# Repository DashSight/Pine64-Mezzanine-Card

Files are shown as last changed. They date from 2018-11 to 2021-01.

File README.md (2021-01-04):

# Pine64 Mezzanine Card

OSH Open Source Hardware Logo
Qwiic Logo

This is a open source hardware mezzanine card/hat/expansion board for the [SOPINE A64](https://www.pine64.org/sopine/) Single Board Computer (SBC). The project is developed using the open source EDA tool [KiCAD](http://kicad-pcb.org/).

This card adds the following features to the Pine64 SBC:

* OBDII Connection to communicate with a car's onboard diagnostics
  * SAE J1850 PWM
  * SAE J1850 VPW
  * ISO 9141-2
  * ISO 14230 KWP2000
  * ISO 15765 CAN
* GPS receiver to obtain current location
  * Battery backup to reduce power up time
  * External powered antenna to increase accuracy
  * PPS to increase accuracy of clock
* Inertial Measurement Unit (IMU) to detect acceleration and body roll
  * Connected via SPI
* 3 x [Qwiic](https://www.sparkfun.com/qwiic) connectors to expose other devices via I2C
* Support for a [1 wire temperature sensor](https://www.sparkfun.com/products/11050)

The version 3.0 is baed on the [ELM327](https://www.elmelectronics.com/ic/elm327/), the [u-blox NEO-M9N](https://www.u-blox.com/en/product/neo-m9n-module) Integrate Circuits (ICs) and the [LSM9DS1 IMU](https://www.st.com/en/mems-and-sensors/lsm9ds1.html).

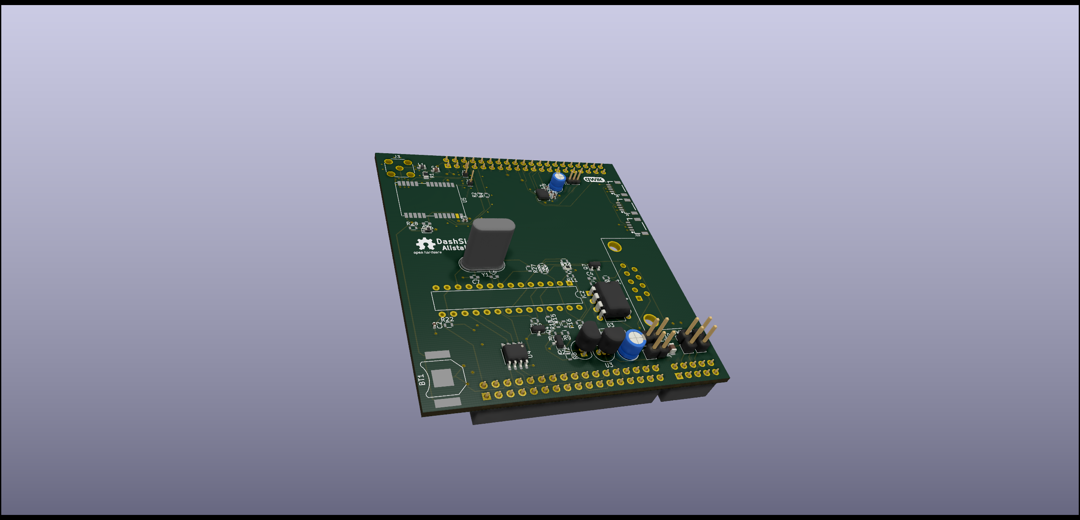
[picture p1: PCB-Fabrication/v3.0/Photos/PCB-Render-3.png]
DashSight Mezzanine Card v3.0 Render


## Licence

The design is licenced under the CERN-OHL-W licence.

The exception to this is the 3rd party [SparkFun libraries](https://github.com/sparkfun/SparkFun-KiCad-Libraries) which are used for the Qwiic connectors in the schematic and PCB. These are released under the [Creative Commons Attribution 4.0 International license](https://creativecommons.org/licenses/by/4.0/).

## v3.0 Production Run

More [pictures of v3.0](https://github.com/DashSight/Pine64-Mezzanine-Card/blob/master/PCB-Fabrication/v3.0/Photos) are avaliable

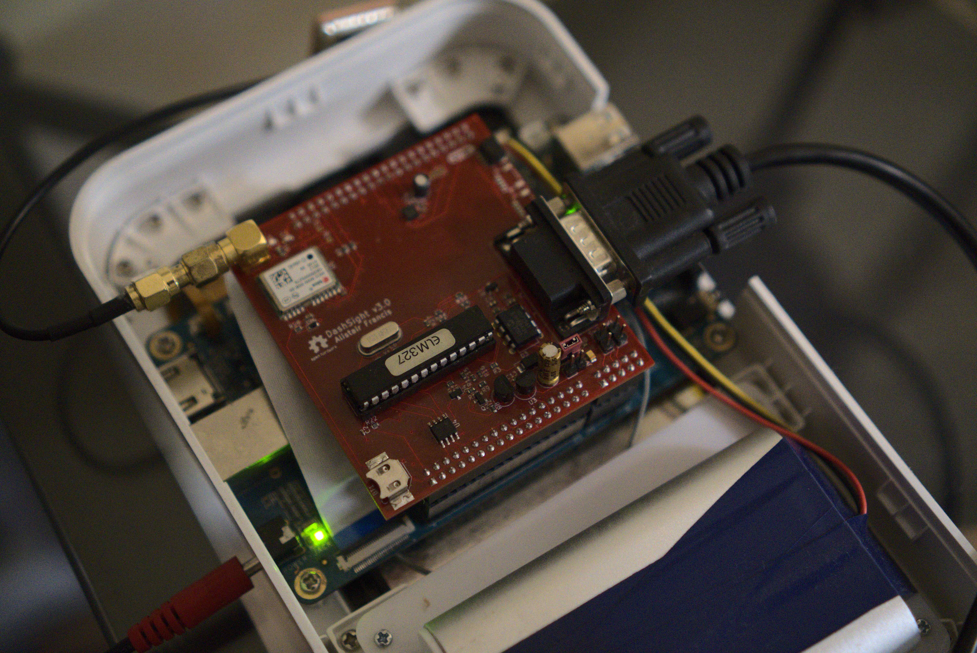
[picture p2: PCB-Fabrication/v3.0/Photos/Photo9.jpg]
DashSight Mezzanine Card Photo 9

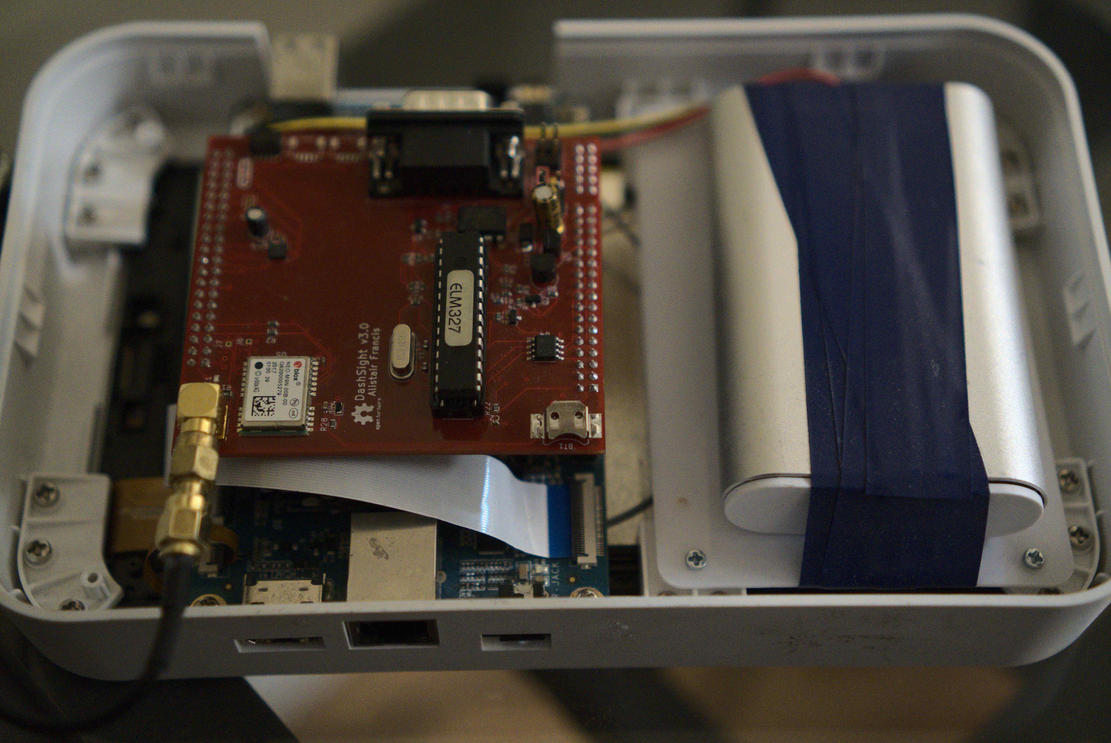
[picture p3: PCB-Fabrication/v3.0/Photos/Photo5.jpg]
DashSight Mezzanine Card Photo 5


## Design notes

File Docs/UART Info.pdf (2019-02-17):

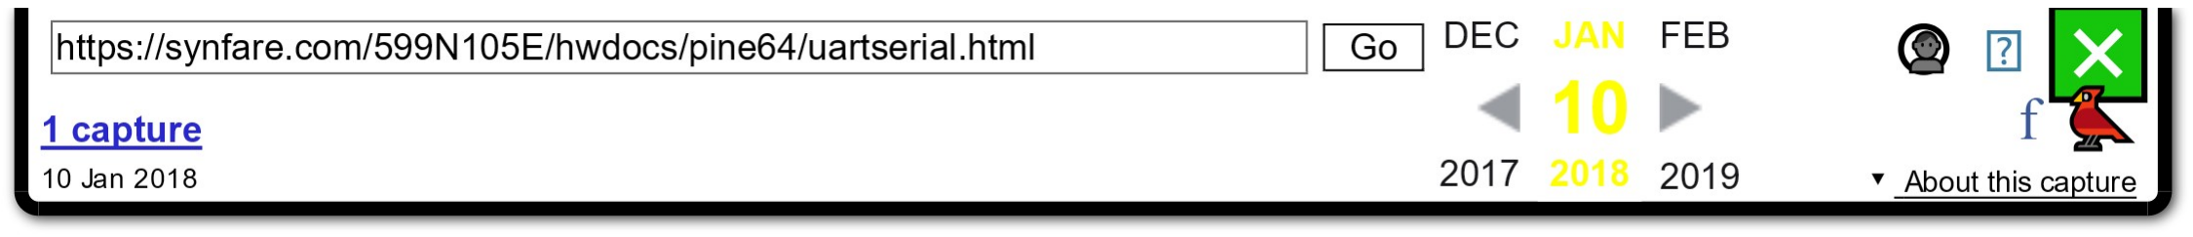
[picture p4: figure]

# UART Serial ports

There are 6 serial ports defined, of which at least 5 can operate with terminals or in any other way that serial ports can be used. Some of the ports have the RTS/CTS handshaking line pair also, as shown. UART0 TX and RX appear on both Euler (J48) and Expansion (J51). Ground connections refer to pins physically near the TX and RX pins; any other Ground pins can be used as well. The serial ports defined are available at the following pins:

UART#

/dev/ttyS# | Tx | Rx | RTS
| | | (output) | CTS
| | | | (input) | GND
0 | X7 | X8 | | | X6 | Voh = 3.3 V nominal. Gated so there is no
| | | | | | back-feeding when power is off.
0 | E29 | E30 | | | E34 | Voh = 3.3 V nominal
1 | B2 | B4 | B6 | B8 | B10 | Voh = 1.8 V nominal
2 | P8 | P10 | E11 | E27 | P6 | Voh = 3.3 V nominal
3 | E24 | E23 | | | E25 | Voh = 2.5 V nominal
3 | T2 | P29 | P31 | (P26) | P30 | Voh = 2.5 V nominal. Alternate connections
| | | | | | seen on some recent kernels. See discussion
| | | | | | below.
4 | E19 | E21 | E18 | E22 | E20 | Voh = 2.5 V nominal
S- | W9 | W11 | | | W12 | Voh = 1.8 V nominal
Adafruit USB cable (#954) | White
| (Rx) | Green
| | (Tx) | | | Black
| | | | | (Gnd) | (Red is 5V, NC)
Sparkfun USB cable (CAB-12977) | Yellow
| (Rx) | Orange
| | (Tx) | | | Black
| | | | | (Gnd) | (Red is 5V, NC)

Adafruit FTDI
Serial TTL-232 USB cable (#70) | Yellow
| (Rx) | Orange
| | (Tx) | Brown
| | | (CTS) | Green
| | | | (RTS) | Black
| | | | | (Gnd) | (Red is 5V, NC)
DE9M (DTE) pin # | 3 | 2 | 7 | 8 | 5 | (Via level translator)

DB25M (DTE)
pin # | 2 | 3 | 4 | 5 | 7 | (Via level translator)

The signal level on UARTs 0 and 2 is 3.3V, on UARTs 3 and 4 it is 2.5V, and on UARTs 1 and S it is 1.8 V. so the connections to a standard DE9 plug shown will have to be made via level translators in an ST3232 or similar that converts from RS-232 Mark and Space to H and L.

Pine A64+ UARTs | https://web.archive.org/web/20180110102911/https://synfare.com/599N...
1 of 2 | 10/02/2019, 9:33 pm

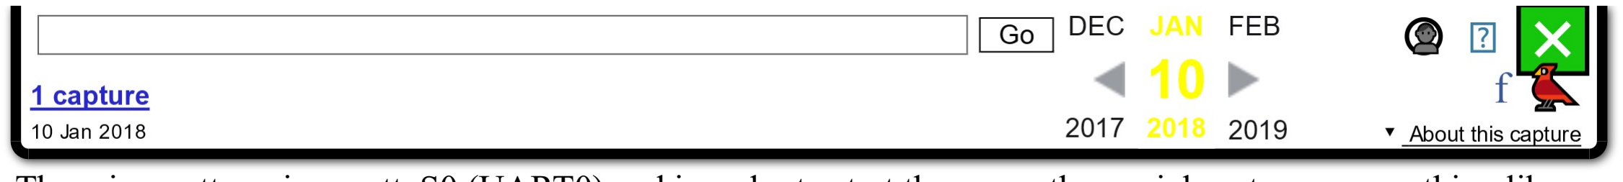
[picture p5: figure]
Note that UART1 (/dev/tty; output voltage is on the low

not be directly available if the wireless card is being used. These are also both in the 1.8 V system so the high

There is a getty going on ttyS0 (UART0) and in order to start these on other serial ports, use something like what is shown here for ttyS2 here:

systemctl enable serial-getty@ttyS2.service
systemctl start serial-getty@ttyS2.service

Similarly, in order to remove the getty the equivalent commands are:

systemctl stop serial-getty@ttyS2.service
systemctl disable serial-getty@ttyS2.service

### Where has uart3 moved?

2017-11-13: For some reason the /dev/ttyS3 seemed inoperative on the more recent kernels. (3.10.105-bsp-1.2-ayufan-118). Code for opening, writing and reading didn't fail, but nothing appeared on the wires. Some more investigation of the GPIO control registers for pins PD0 and PD1 showed that these two are at function 7 which means they are disabled. Notably, bits PD5, PD4, PD3, and PD2, which are associated with UART4, were at the expected function 3, which is the serial-port settings. Changing these settings to 3 for PD1 and PD0 was all that was needed for the UART3 to start emitting and receiving signals on the assigned wires, PD0 at pin E24 for transmission, and PD1 at pin E23 for reception.

Inspection of the device-tree file, indicates that the UART3 is actually enabled on PH4=Tx (T2) PH5=Rx (P29) PH6=RTS (P31) PH7=CTS (P26). Now that is somewhat less convenient since PH4, transmit data, is one of the Touchpad connector pins, identified as at connection T2. Unless this is broken out, it will not make the UART3 particularly useful... Besides that, the PH7 is already being used for a codec output of some sort, and is being allocated, as per /sys/kernel/debug/gpio.

The file checku.c contains the code I used for performing this check and making the changes. This code is similar to what is shown on the page for /dev/mem gpio handling.

This function shows the functions of all the first 8 PD and PH ports, PD7 (GPIO103, at pin E28) and PD6 (GPIO102 at pin E26) are shown as function 7, disabled, also. This makes sense, since these are unallocated, and available for us to use. PH7 (GPIO231 at pin P26) shows as 1, output, and the rest of PH6-PH0 are function 2. Now for PH3-PH0 this function means they operate as the two i2c busses, so that has to remain the same!

Now, it turns out, that when any gpio not otherwise allocated, is exported via sysfs (see the sysfs gpio details), its function is not changed. So if it started out as disabled, it remains disabled, even though the direction file (/sys/class/gpio/gpio103/direction) says "in". Only when this direction file is written with the values "in" or "out" does this register value change, to 0 for input and 1 for output. (
Allwinner_A64_User_Manual_V1.0.pdf, section 3.21.2.19, page 384) These settings also remain after the gpio is unexported, and thus a gpio will have the same direction after another exporting as it had before. This was noted as a kind of bug in the forum. To Pine 64+ main page

Powered by Apache

Valid XHTML 1.0!

Pine A64+ UARTs | https://web.archive.org/web/20180110102911/https://synfare.com/599N...
2 of 2 | 10/02/2019, 9:33 pm

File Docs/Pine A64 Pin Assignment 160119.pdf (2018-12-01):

Pi-2 Connector

Page 1

Pi-2 Connector
| | 3.3V | | 1 | 2 | | | 5V
PH3 | TWI1_SDA GPIO 2 | I2C1_SDA | 3 | 4 | 5V
PH2 | TWI1_SCK GPIO 3 | I2C1_SCL | 5 | 6 | GND
PL10 | S_PWM | GPIO 4 | GPCLK0 | 7 | 8 | UART_TXD GPIO 14 | UART2_TX PB0
GND | 9 | 10 | UART_RXD GPIO 15 | UART2_RX PB1
PC7 | | GPIO 17 | | 11 | 12 | | GPIO 18 | | PC8
PH9 | | GPIO 27 | | 13 | 14 | | | GND
PC12 | | GPIO 22 | | 15 | 16 | | GPIO 23 | | PC13
| | 3.3V | | 17 | 18 | | GPIO 24 | | PC14
PC0 | SPI0_MOSI GPIO 10 | SPI_MOSI | 19 | 20 | GND
PC1 | SPI0_MISO GPIO 9 | SPI_MISO | 21 | 22 | GPIO 25 | PC15
PC2 | SPI0_CLK | GPIO 11 | SPI_SCLK | 23 | 24 | SPI_CE0 | GPIO 8 | SPI0_CS | PC3
| | GND | | 25 | 26 | SPI_CE1 | GPIO 7 | | PH7
PL9 | TWI_SDA | | ID_SD | 27 | 28 | ID_SC | | TWI_SCK | PL8
PH5 | | GPIO 5 | | 29 | 30 | | | GND
PH6 | | GPIO 6 | | 31 | 32 | | GPIO 12 | | PC4
PC5 | | GPIO 13 | | 33 | 34 | | | GND
PC9 | | GPIO 19 | | 35 | 36 | | GPIO 16 | | PC6
PC16 | | GPIO 26 | | 37 | 38 | | GPIO 20 | | PC10
| | GND | | 39 | 40 | | GPIO 21 | | PC11

Euler "e" Connector

Page 2

Euler "e" Connector
| | 3.3V | 1 | 2 | DC IN
Lithium Batt+ | 3 | 4 | DC IN
Temp Sensor | 5 | 6 | GND
PL11 | IR_RX | | 7 | 8 | 5V
GND | 9 | 10 | SPDIF | OWA_OUT PH8
PB3 | I2S_MCK | | 11 | 12 | I2S_SYNC | PB4
PB5 | I2S_BCK | | 13 | 14 | GND
PB6 | I2S_DOUT | | 15 | 16 | I2S_DIN | PB7
3.3V | 17 | 18 | UART4_RTS PD4
PD2 | SPI1_MOSI UART4_TX | 19 | 20 | GND
PD3 | SPI1_MISO UART4_RX | 21 | 22 | UART4_CTS PD5
PD1 | SPI1_CLK | UART3_RX | 23 | 24 | UART3_TX SPI1_CS | PD0
| | GND | 25 | 26 | | PD6
PB2 | | | 27 | 28 | | PD7
PB8 | | UART0_TX | 29 | 30 | UART0_RX | PB9
EAROUTP | 31 | 32 | EAROUT_N
N.C. | 33 | 34 | GND

Exp Connector

Page 3

Exp Connector
3.3V | 1 | 2 | System LED | PL7
Charger LED | 3 | 4 | Reset Sw
Pwr/Stb Sw | 5 | 6 | GND
PB8 | UART0_TX | 7 | 8 | UART0_RX PB9
GND | 9 | 10 | KeyADC

Wifi_BT

Page 4

Wifi/BT Connector
GND | 1 | 2 | BT-UART-RX | UART1-TX | PG6
PG0 | SDC1-CK | SDIO-CLK | 3 | 4 | BT-UART-TX | | UART1-RX | PG7
GND | 5 | 6 | BT-UART-CTS | UART1-RTS PG8
PG1 | SDC1-CMD | SDIO-CMD | 7 | 8 | BT-UART-RTS | UART1-CTS PG9
PG2 | SDC1-D0 | SDIO-D0 | 9 | 10 | BT-PCM-SYNC | PCB1-SYNC AIF3-SYNC PG10
PG3 | SDC1-D1 | SDIO-D1 | 11 | 12 | BT-PCM-CLK | PCB1-BCLK AIF3-BCLK | PG11
PG4 | SDC1-D2 | SDIO-D2 | 13 | 14 | BT-PCM-DIN | PCB1-DOUT AIF3-DOUT PG12
PG5 | SDC1-D3 | SDIO-D3 | 15 | 16 | BT-PCM-DOUT | PCB1-DIN | AIF3-DIN | PG13
PL2 | S-UART-TX | WL-REG-ON | 17 | 18 | | GND
PL3 | S-UART-RX | WL-WAKE-AP | 19 | 20 | BT-WAKE-AP | S-JTAG-CK PL5
X32KFOUT | AP-CK32KO | 21 | 22 | BT-RST-N | S-JTAG-MS PL4
GND | 23 | 24 | AP-WAKE-BT | S-JTAG-DO PL6
VCC | 25 | 26 | IOVCC

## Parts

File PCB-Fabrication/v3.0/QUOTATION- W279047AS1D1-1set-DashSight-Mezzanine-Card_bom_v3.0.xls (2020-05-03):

Reference | Value | Footprint | Part Number | Field4 | Amount | 1sets | Total | update
IC2 | ELM327 | Housings_DIP:DIP-28_W7.62mm | ED281DT |  | 1 | $0.525 | $0.525 | ED281DT
Y1 | 4.0MHz | Crystals:Crystal_HC49-U_Vertical | ECS-040-20-4X-DU |  | 1 | $1.260 | $1.260 | 5-7work days
C6 | 27pF | Capacitors_SMD:C_0603 | CC0603JRNPO9BN270 |  | 1 | $0.525 | $0.525
C7 | 27pF | Capacitors_SMD:C_0603 | CC0603JRNPO9BN270 |  | 1 | $0.525 | $0.525
U1 | MCP2561-E/P | Housings_DIP:DIP-8_W7.62mm | MCP2561-E/P |  | 1 | $1.890 | $1.890 | 5-7work days
C2 | 0.1uF | Capacitor_SMD:C_0402_1005Metric | CC0402KRX7R7BB104 |  | 1 | $0.525 | $0.525
R3 | 4.7K | Resistors_SMD:R_0603 | RC0603FR-074K7L |  | 1 | $0.315 | $0.315
J4 | OBD2-DB9_Male | Connector_Dsub:DSUB-9_Male_Horizontal_P2.77x2.84mm_EdgePinOffset4.94mm_Housed_MountingHolesOffset7.48mm | A-DS 09 A/KG-T2S |  | 1 | $1.575 | $1.575 | 5-7work days
R5 | 100 | Resistors_SMD:R_0603 | RC0603JR-07100RL |  | 1 | $0.315 | $0.315
R6 | 100 | Resistors_SMD:R_0603 | RC0603JR-07100RL |  | 1 | $0.315 | $0.315
C3 | 560pF | Capacitors_SMD:C_0603 | C0603C561K5RACTU |  | 1 | $0.525 | $0.525
C4 | 560pF | Capacitors_SMD:C_0603 | C0603C561K5RACTU |  | 1 | $0.525 | $0.525
R11 | 47K | Resistors_SMD:R_0603 | RC0603JR-0747KL |  | 1 | $0.315 | $0.315
R12 | 10K | Resistor_SMD:R_0603_1608Metric | RC0603FR-0710KL |  | 1 | $0.315 | $0.315
U2 | LM317L_TO92 | TO_SOT_Packages_THT:TO-92_Inline_Narrow_Oval | LM317LZX |  | 1 | $1.050 | $1.050 | 5-7work days
R15 | 2.2K | Resistors_SMD:R_0603 | RC0603JR-072K2L |  | 1 | $0.315 | $0.315
R16 | 1.8K | Resistors_SMD:R_0603 | RC0603FR-071K8L |  | 1 | $0.525 | $0.525
R13 | 470 | Resistors_SMD:R_0603 | RC0603JR-07470RL |  | 1 | $0.315 | $0.315
R8 | 470 | Resistors_SMD:R_0603 | RC0603JR-07470RL |  | 1 | $0.315 | $0.315
Q2 | 2N3906 | Package_TO_SOT_SMD:SOT-23 | MMBT3904 |  | 1 | $0.525 | $0.525
R9 | 10K | Resistors_SMD:R_0603 | RC0603FR-0710KL |  | 1 | $0.315 | $0.315
D1 | 1N4148 | Diodes_SMD:D_SOD-123 | 1N4148W-TP |  | 1 | $0.525 | $0.525
R17 | 4.7K | Resistors_SMD:R_0603 | RC0603FR-074K7L |  | 1 | $0.315 | $0.315
Q4 | 2N3904 | Package_TO_SOT_SMD:SOT-23 | MMBT3904 |  | 1 | $0.525 | $0.525
R20 | 4.7K | Resistors_SMD:R_0603 | RC0603FR-074K7L |  | 1 | $0.315 | $0.315
R18 | 10K | Resistors_SMD:R_0603 | RC0603FR-0710KL |  | 1 | $0.315 | $0.315
R10 | 22K | Resistors_SMD:R_0603 | RC0603FR-0722KL |  | 1 | $0.315 | $0.315
R21 | 10K | Resistors_SMD:R_0603 | RC0603FR-0710KL |  | 1 | $0.315 | $0.315
R23 | 22K | Resistors_SMD:R_0603 | RC0603FR-0722KL |  | 1 | $0.315 | $0.315
Q3 | 2N3906 | Package_TO_SOT_SMD:SOT-23 | MMBT3904 |  | 1 | $0.525 | $0.525
R22 | 4.7K | Resistors_SMD:R_0603 | RC0603FR-074K7L |  | 1 | $0.315 | $0.315
R19 | 10K | Resistors_SMD:R_0603 | RC0603FR-0710KL |  | 1 | $0.315 | $0.315
R14 | 47K | Resistors_SMD:R_0603 | RC0603JR-0747KL |  | 1 | $0.315 | $0.315
D2 | 1N4148 | Diodes_SMD:D_SOD-123 | 1N4148W-TP |  | 1 | $0.525 | $0.525
Q1 | 2N3904 | Package_TO_SOT_SMD:SOT-23 | MMBT3904 |  | 1 | $0.525 | $0.525
Q5 | 2N3904 | Package_TO_SOT_SMD:SOT-23 | MMBT3904 |  | 1 | $0.525 | $0.525
R7 | 4.7K | Resistors_SMD:R_0603 | RC0603FR-074K7L |  | 1 | $0.315 | $0.315
Q6 | 2N3904 | Package_TO_SOT_SMD:SOT-23 | MMBT3904 |  | 1 | $0.525 | $0.525
R24 | 2.2K | Resistors_SMD:R_0603 | RC0603JR-072K2L |  | 1 | $0.315 | $0.315
R29 | 510 | Resistors_SMD:R_0603 | RC0603JR-07510RL |  | 1 | $0.315 | $0.315
Q7 | 2N3904 | Package_TO_SOT_SMD:SOT-23 | MMBT3904 |  | 1 | $0.525 | $0.525
R25 | 2.2K | Resistors_SMD:R_0603 | RC0603JR-072K2L |  | 1 | $0.315 | $0.315
R30 | 510 | Resistors_SMD:R_0603 | RC0603JR-07510RL |  | 1 | $0.315 | $0.315
R26 | 47K | Resistors_SMD:R_0603 | RC0603JR-0747KL |  | 1 | $0.315 | $0.315
R27 | 33K | Resistors_SMD:R_0603 | CRCW060333K0FKEAC |  | 1 | $0.525 | $0.525
D3 | 1N5819 | Diodes_SMD:D_SMA | 1N5819 |  | 1 | $0.525 | $0.525
J1 | Pi2 Connector | Pin_Headers:Pin_Header_Straight_2x20_Pitch2.54mm | PPPC202LFBN-RC |  | 1 | $1.050 | $1.050
J2 | Euler Connector | Pin_Headers:Pin_Header_Straight_2x17_Pitch2.54mm | PPPC172LFBN-RC |  | 1 | $1.050 | $1.050
C8 | 0.1uF | Capacitors_SMD:C_0402 | CC0402KRX7R7BB104 |  | 1 | $0.525 | $0.525
C12 | 2.2uF 50V | Capacitor_THT:CP_Radial_D5.0mm_P2.50mm | UFW1H2R2MDD1TD |  | 1 | $0.840 | $0.840 | 5-7work days
C13 | 0.1uF 50V | Capacitor_SMD:C_0402_1005Metric | UMK105BJ104KV-F |  | 1 | $0.525 | $0.525
U3 | LP2950-3.0_TO92 | Package_TO_SOT_THT:TO-92_Inline | LP2950-50LPRE3 |  | 1 | $1.050 | $1.050 | 3300pcs in stock
C10 | 0.1uF | Capacitor_SMD:C_0402_1005Metric | CC0402KRX7R7BB104 |  | 1 | $0.525 | $0.525
C11 | 4.7uF 10V | Capacitor_SMD:C_0805_2012Metric | TAJR475M010RNJ |  | 1 | $0.840 | $0.840 | 2500pcs in stock
U4 | ADuM1201AR | Housings_SOIC:SOIC-8_3.9x4.9mm_Pitch1.27mm | ADuM1201AR |  | 1 | $2.100 | $2.100 | provide ADUM1201ARZ-RL7
JP2 | Vbat-JP | Pin_Headers:Pin_Header_Straight_1x02_Pitch2.54mm | 61300211121 |  | 1 | $0.315 | $0.315
JP1 | DCIn-JP | Pin_Headers:Pin_Header_Straight_1x02_Pitch2.54mm | 61300211121 |  | 1 | $0.315 | $0.315
R2 | 470 | Resistors_SMD:R_0603 | RC0603JR-07470RL |  | 1 | $0.315 | $0.315
D4 | 0.5A/40V/420mV | Resistors_SMD:R_0402 | VSKY05401006-G4-08 |  | 1 | $1.155 | $1.155 | RB551SS-30T2R size 0603 5-7work days
BT1 | 6.8mm-Coin-Cell | DashSight-PCB-Footprints:BatteryHolder_Keystone_2998_1x6.8mm | 2998 |  | 1 | $1.050 | $1.050 | 5-7work days
C14 | 1uF | Capacitors_SMD:C_0603 | CC0603ZRY5V7BB105 |  | 1 | $0.525 | $0.525
U5 | NEO-M9N | RF_GPS:ublox_NEO | https://www.u-blox.com/sites/default/files/NEO-M8-FW3_DataSheet_%28UBX-15031086%29.pdf |  | 1 | $35.000 | $35.000 | NEO-M9N two weeks
R4 | 470 | Resistors_SMD:R_0603 | RC0603JR-07470RL |  | 1 | $0.315 | $0.315
R28 | 1K | Resistors_SMD:R_0603 | RC0603FR-071KL |  | 1 | $0.525 | $0.525
J5 | Conn_02x05_Odd_Even | Connector_PinHeader_2.54mm:PinHeader_2x05_P2.54mm_Vertical | PPPC052LFBN-RC |  | 1 | $0.525 | $0.525
SW1 | SW_Push | Connector_PinHeader_2.54mm:PinHeader_1x02_P2.54mm_Vertical | 61300211121 |  | 1 | $0.315 | $0.315
SW2 | SW_Push | Connector_PinHeader_2.54mm:PinHeader_1x02_P2.54mm_Vertical | 61300211121 |  | 1 | $0.315 | $0.315
R1 | 10 | Resistor_SMD:R_0805_2012Metric | SR0805KR-7W10RL |  | 1 | $0.330 | $0.330 | 3-4work days
C1 | 47pF | Capacitor_SMD:C_0603_1608Metric | C0603C104M4RACTU |  | 1 | $0.525 | $0.525
J3 | Conn_Coaxial | Connectors:SMA_THT_Jack_Straight | CONREVSMA002-G |  | 1 | $5.040 | $5.040 | 5-7work days
L1 | 30Ohm/1.8A | Inductor_SMD:L_0603_1608Metric | 744786127A |  | 1 | $0.840 | $0.840 | 5-7work days
C5 | 0.1uF | Capacitor_SMD:C_0402_1005Metric | CC0402KRX7R7BB104 |  | 1 | $0.525 | $0.525
U6 | LSM9DS1 | Package_LGA:LGA-24L_3x3.5mm_P0.43mm | LSM9DS1 |  | 1 | $5.250 | $5.250 | provide LSM9DS1TR
C18 | 10uF | Capacitor_THT:CP_Radial_D4.0mm_P1.50mm | UMP1A100MDD1TP |  | 1 | $1.260 | $1.260 | 5-7work days
C17 | 0.1uF | Capacitor_SMD:C_0402_1005Metric | CC0402KRX7R7BB104 |  | 1 | $0.525 | $0.525
C9 | 10nF (16V) | Capacitor_SMD:C_0402_1005Metric | C0402C103K4RACTU |  | 1 | $0.525 | $0.525
C15 | 0.1uF | Capacitor_SMD:C_0402_1005Metric | CC0402KRX7R7BB104 |  | 1 | $0.525 | $0.525
C16 | 0.1uF | Capacitor_SMD:C_0402_1005Metric | CC0402KRX7R7BB104 |  | 1 | $0.525 | $0.525
R38 | 2.2K | Resistor_SMD:R_0603_1608Metric | RC0603FR-072K2L |  | 1 | $0.315 | $0.315
R37 | 2.2K | Resistor_SMD:R_0603_1608Metric | RC0603FR-072K2L |  | 1 | $0.315 | $0.315
J7 | Reset | Connector_PinHeader_1.00mm:PinHeader_1x01_P1.00mm_Vertical |  |  | 1 | $0.000 | $0.000 | DNP
J6 | Safeboot | Connector_PinHeader_1.00mm:PinHeader_1x01_P1.00mm_Vertical |  |  | 1 | $0.000 | $0.000 | DNP
J8 | QWIIC_CONNECTORJS-1MM | DashSight:qwiic_connector | PRT-14417-ND | Qwiic0 | 1 | $1.365 | $1.365 | PRT-14417 7-10work days
J9 | QWIIC_CONNECTORJS-1MM | DashSight:qwiic_connector | PRT-14417-ND | Qwiic3 | 1 | $1.365 | $1.365 | PRT-14417 7-10work days
J10 | QWIIC_CONNECTORJS-1MM | DashSight:qwiic_connector | PRT-14417-ND | Qwiic1 | 1 | $1.365 | $1.365 | PRT-14417 7-10work days
J14 | 1W-PC16 | Connector_PinHeader_1.27mm:PinHeader_1x03_P1.27mm_Vertical |  |  | 1 | $0.000 | $0.000 | DNP
 |  |  |  |  |  | 1SET | $92.555
 |  |  |  |  |  | provide according to Part Number

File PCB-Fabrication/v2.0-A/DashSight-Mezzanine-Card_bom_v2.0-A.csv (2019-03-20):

Component | Description | Part | References | Value | Footprint | Quantity Per PCB | Datasheet
1 | Single-cell battery | Battery_Cell | BT1 | 6.8mm-Coin-Cell | BatteryHolder_Keystone_2998_1x6.8mm | 1 | 2998
2 | Polarized capacitor, US symbol | CP1 | C2 C5 C8 C10 | 0.1uF | C_0402 | 4 | CC0402KRX7R7BB104
3 | Polarized capacitor, US symbol | CP1 | C13 | 0.1uF 50V | C_0402 | 1 | UMK105BJ104KV-F
4 | Polarized capacitor, US symbol | CP1 | C1 C9 C14 | 1uF | C_0603 | 3 | CC0603ZRY5V7BB105
5 | Polarized capacitor, US symbol | CP1 | C12 | 2.2uF 50V | CP_Radial_D5.0mm_P2.50mm | 1 | UFW1H2R2MDD1TD
6 | Polarized capacitor, small US symbol | CP1_Small | C6 C7 | 27pF | C_0603 | 2 | CC0603JRNPO9BN270
7 | Polarized capacitor, US symbol | CP1 | C11 | 4.7uF 10V | C_0805 | 1 | TAJR475M010RNJ
8 | Polarized capacitor, US symbol | CP1 | C3 C4 | 560pF | C_0603 | 2 | C0603C561K5RACTU
9 | Schottky diode | D_Schottky | D4 | 0.5A/40V/420mV | R_0402 | 1 | VSKY05401006-G4-08
10 | Diode | D | D1 D2 | 1N4148 | D_SOD-123 | 2 | 1N4148W-TP
11 | Diode | D | D3 | 1N5819 | D_SMA | 1 | 1N5819
12 | Ferrite bead | Ferrite_Bead | FB1 | 600Ohm/100MHz | L_0402 | 1 | 74279279
13 |  | ELM327 | IC2 | ELM327 | DIP-28_W7.62mm | 1 | ED281DT
14 |  | XM1110 | IC1 | XM1110 | Sierra_XM11X0 | 1 | XM1110_1103886
15 | coaxial connector (BNC, SMA, SMB, SMC, Cinch/RCA, ...) | Conn_Coaxial | J3 | Conn_Coaxial | SMA_THT_Jack_Straight | 1 | CONREVSMA002-G
16 | Generic connector, double row, 02x17, odd/even pin numbering scheme (row 1 odd numbers, row 2 even numbers), script generated (kicad-library-utils/schlib/autogen/connector/) | Conn_02x17_Odd_Even | J2 | Euler Connector | Pin_Header_Straight_2x17_Pitch2.54mm | 1 | PPPC172LFBN-RC
17 | Generic connector, double row, 02x20, odd/even pin numbering scheme (row 1 odd numbers, row 2 even numbers), script generated (kicad-library-utils/schlib/autogen/connector/) | Conn_02x20_Odd_Even | J1 | Pi2 Connector | Pin_Header_Straight_2x20_Pitch2.54mm | 1 | PPPC202LFBN-RC
18 | Jumper, normally closed | Jumper | JP1 | DCIn-JP | Pin_Header_Straight_1x02_Pitch2.54mm | 1 | 61300211121
19 | Jumper, normally closed | Jumper | JP2 | Vbat-JP | Pin_Header_Straight_1x02_Pitch2.54mm | 1 | 61300211121
20 | Capacitor symbol for simulation only | INDUCTOR | L1 | 33nH | L_0603 | 1 | MHQ1005P33NJT000
21 | 40V Vce, 0.2A Ic, NPN, Small Signal Transistor, TO-92 | 2N3904 | Q1 Q4 Q5 Q6 Q7 | 2N3904 | TO-92_Molded_Narrow | 5 | 2N3904
22 | -40V Vce, -0.2A Ic, PNP, Small Signal Transistor, TO-92 | 2N3906 | Q2 Q3 | 2N3906 | TO-92_Molded_Narrow | 2 | 2N3906
23 | Resistor | R | R16 | 1.8K | R_0603 | 1 | RC0603FR-071K8L
24 | Resistor | R | R5 R6 | 100 | R_0603 | 2 | RC0603JR-07100RL
25 | Resistor, small symbol | R_Small | R1 R9 R12 R18 R19 R21 | 10K | R_0603 | 6 | RC0603FR-0710KL
26 | Resistor, small symbol | R_Small | R28 | 1K | R_0603 | 1 | RC0603FR-071KL
27 | Resistor | R | R15 R24 R25 | 2.2K | R_0603 | 3 | RC0603JR-072K2L
28 | Resistor | R | R10 R23 | 22K | R_0603 | 2 | RC0603FR-0722KL
29 | Resistor | R | R27 | 33K | R_0603 | 1 | CRCW060333K0FKEAC
30 | Resistor | R | R3 R7 R17 R20 R22 | 4.7K | R_0603 | 5 | RC0603FR-074K7L
31 | Resistor, small symbol | R_Small | R2 R4 R8 R13 | 470 | R_0603 | 4 | RC0603JR-07470RL
32 | Resistor | R | R11 R14 R26 | 47K | R_0603 | 3 | RC0603JR-0747KL
33 | Resistor | R | R29 R30 | 510 | R_0603 | 2 | RC0603JR-07510RL
34 | Dual-channel digital isolator, bidirectional communication, 3V/5V level translation, SOIC-8 | ADuM1201AR | U4 | ADuM1201AR | SOIC-8_3.9x4.9mm_Pitch1.27mm | 1 | ADuM1201AR
35 | 100mA 35V Adjustable Linear Regulator, TO-92 | LM317L_TO92 | U2 | LM317L_TO92 | TO-92_Inline_Narrow_Oval | 1 | LM317LZX
36 | Positive 100mA 30V Linear Micropower Voltage Regulator, Fixed Output 3.0V, TO-92 | LP2950-3.0_TO92 | U3 | LP2950-3.0_TO92 | TO-92_Inline_Narrow_Oval | 1 | LP2950-50LPRE3
37 |  | MCP2561-E_P | U1 | MCP2561-E/P | DIP-8_W7.62mm | 1 | MCP2561-E/P
38 | Two pin crystal | Crystal | Y1 | 4.0MHz | Crystal_HC49-U_Vertical | 1 | ECS-040-20-4X-DU
Component Groups: | 38
Component Count: | 70
Fitted Components: | 70
Number of PCBs: | 1
Total components: | 70
Schematic Version: | v2.00-A
Schematic Date: | 2019-03-19
BoM Date: | 19/03/2019 10:57:46 PM
Schematic Source: | C:\Users\alist\OneDrive\Documents\DashSight\DashSight-Mezzanine-Card\DashSight-Mezzanine-Card.sch
KiCad Version: | Eeschema (5.1.0)-1

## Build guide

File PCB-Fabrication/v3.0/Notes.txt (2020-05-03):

The component J3 should be facing to the left. That is it should be pointing away from the board, parallel to the headers.

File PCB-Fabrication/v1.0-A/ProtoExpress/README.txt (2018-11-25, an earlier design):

Board thickness: 0.062"
Filenames:
	- README.txt -> This file
	- BOM.xls -> Bill of Materials
	- XY-Data-Assembly.csv -> XY Data and Assembly Drawing
	- Excellon-Drill-File-PTH.drl -> Exellon drill file in ASCII format PTH
	- Excellon-Drill-File-NPTH.drl -> Exellon drill file in ASCII format NPTH
	- DashSight-Mezzanine-Card-Edge.Cuts.gbr -> Gerber File Edge Cuts
	- DashSight-Mezzanine-Card-B.Cu.gbr ->  Gerber File Bottom Copper
	- DashSight-Mezzanine-Card-F.Cu.gbr ->  Gerber File Top Copper
	- DashSight-Mezzanine-Card-B.Fab.gbr ->  Gerber File Bottom Fab
	- DashSight-Mezzanine-Card-F.Fab.gbr ->  Gerber File Top Fab
	- DashSight-Mezzanine-Card-B.Mask.gbr ->  Gerber File Bottom Mask
	- DashSight-Mezzanine-Card-F.Mask.gbr ->  Gerber File Top Mask
	- DashSight-Mezzanine-Card-B.Paste.gbr ->  Gerber File Bottom Paste
	- DashSight-Mezzanine-Card-F.Paste.gbr ->  Gerber File Top Paste
	- DashSight-Mezzanine-Card-B.SilkS.gbr ->  Gerber File Bottom Silk Screen
	- DashSight-Mezzanine-Card-F.SilkS.gbr ->  Gerber File Top Silk Screen

Contact Information:
	Alistair Francis
	alistair@alistair23.me

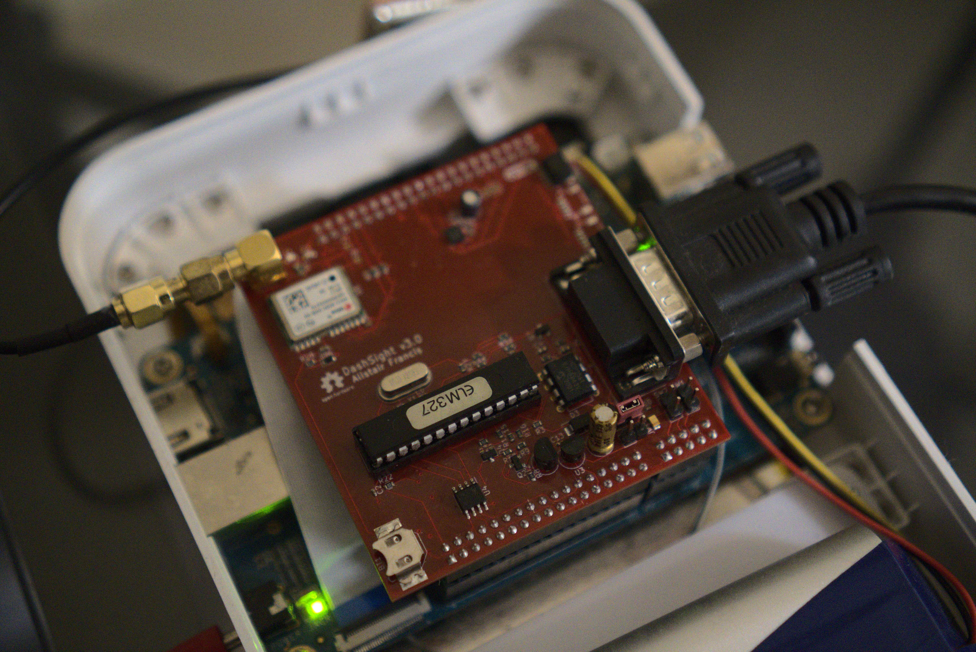
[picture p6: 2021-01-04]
PCB-Fabrication/v3.0/Photos/Photo8.jpg

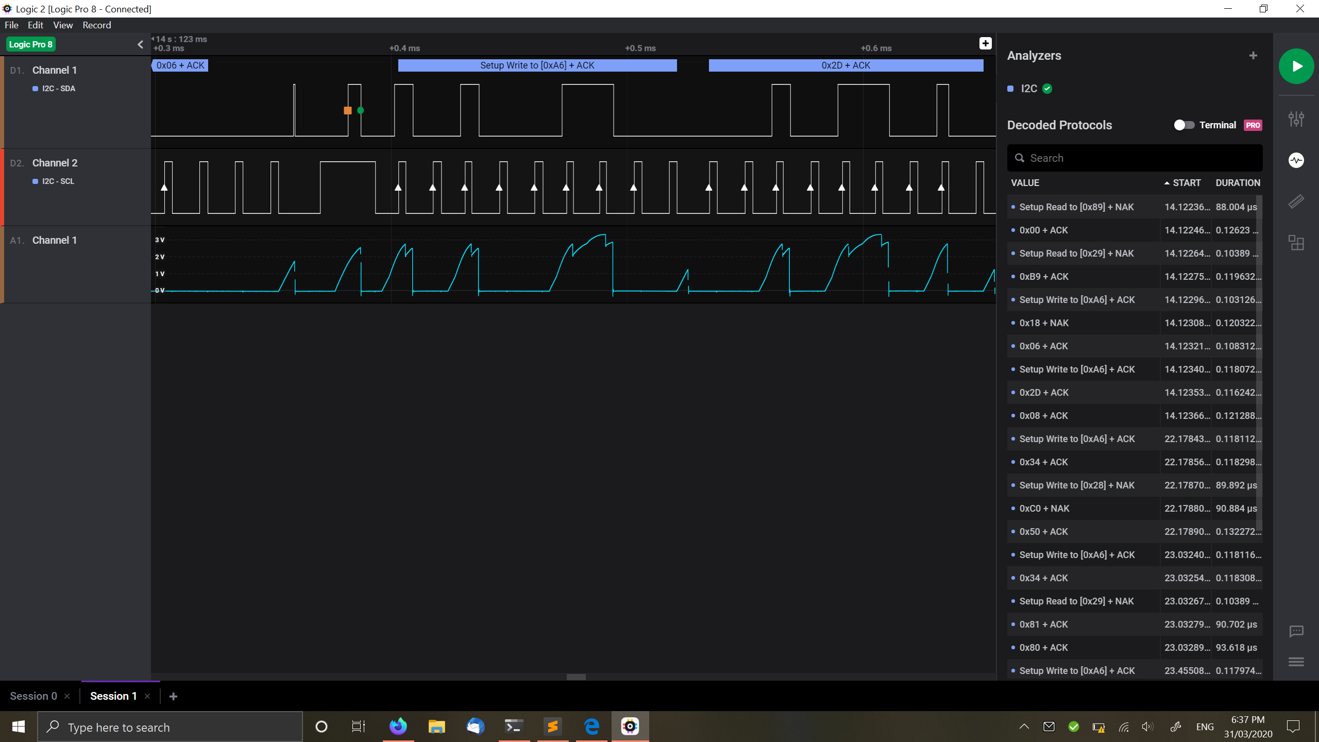
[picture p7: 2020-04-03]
PCB-Fabrication/v2.0-A/Photos/DashSight-Acceleromter-NotWorking-Analouge.png

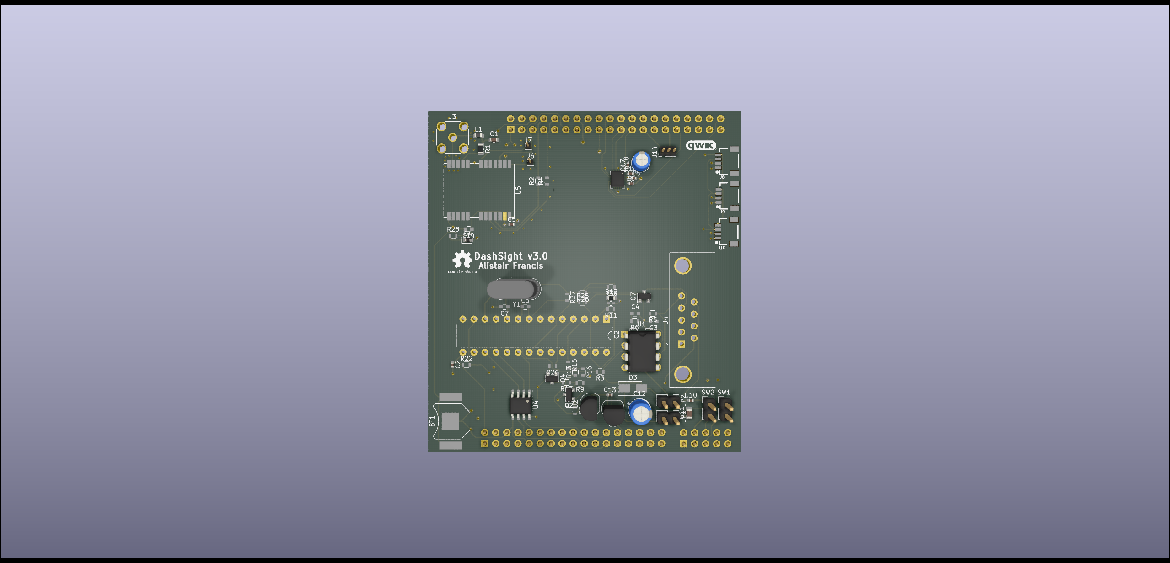
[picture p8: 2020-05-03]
PCB-Fabrication/v3.0/Photos/PCB-Render-2.png

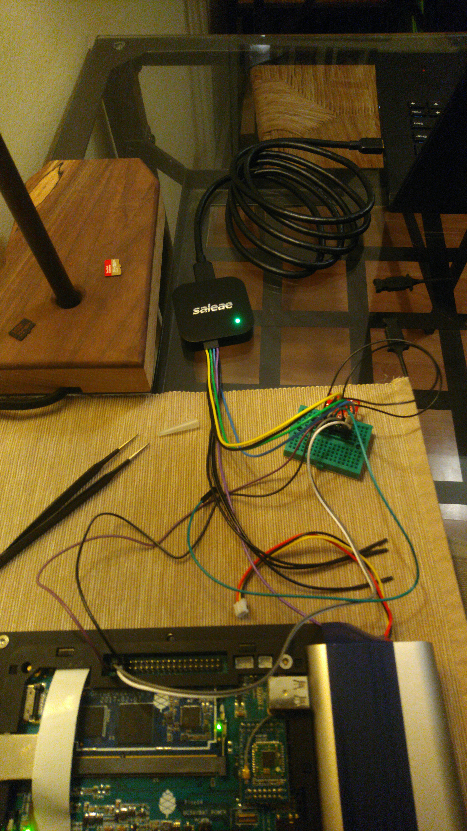
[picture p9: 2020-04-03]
PCB-Fabrication/v2.0-A/Photos/20200330_230413.jpg

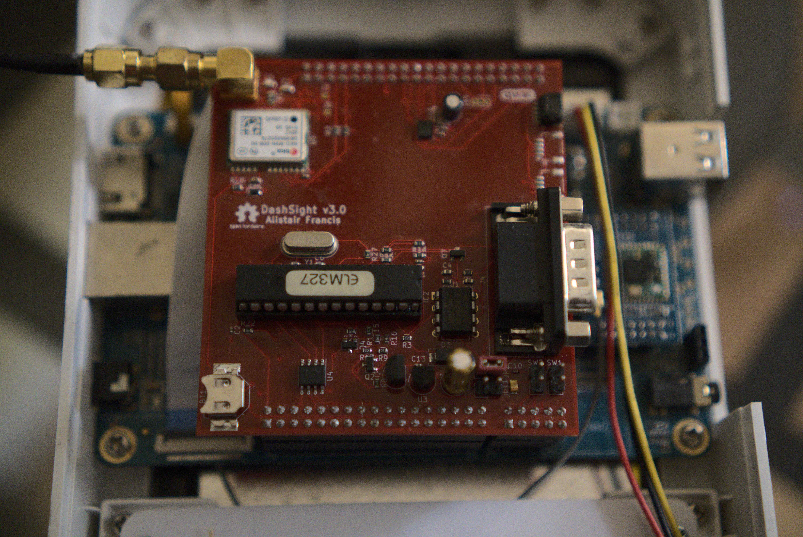
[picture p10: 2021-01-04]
PCB-Fabrication/v3.0/Photos/Photo2.jpg

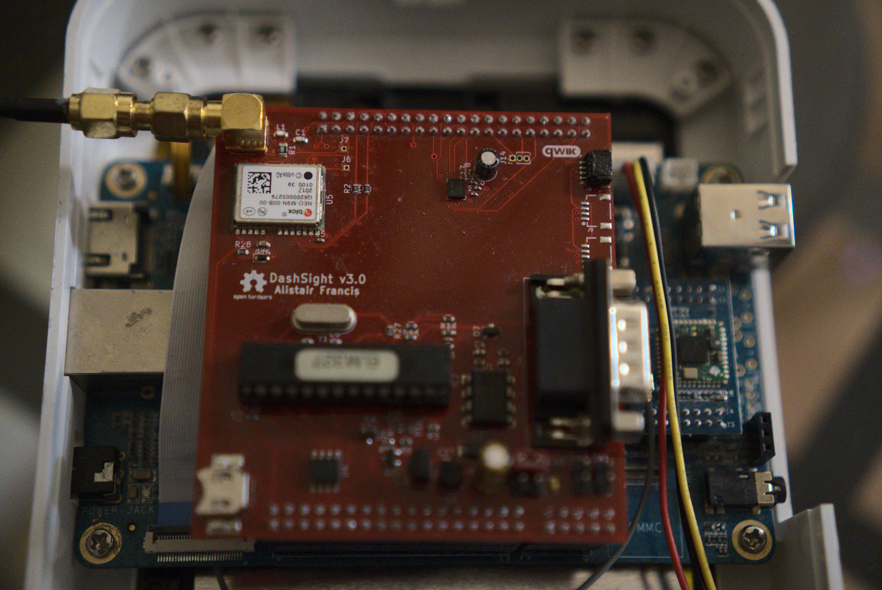
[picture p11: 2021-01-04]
PCB-Fabrication/v3.0/Photos/Photo3.jpg

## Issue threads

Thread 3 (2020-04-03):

Review and fix the GPS PCB implementation

alistair23, 2020-04-03:
Use this for the trace between the antenna and receiver: https://github.com/easyw/RF-tools-KiCAD

alistair23, 2020-04-05:
Some more notes: https://hackaday.com/2016/03/23/michael-ossmann-makes-you-an-rf-design-hero/

alistair23, 2020-04-05:
https://www.electronicdesign.com/technologies/communications/article/21799702/adding-a-gps-chipset-to-your-next-design-is-easy

Closed 2020-04-28.

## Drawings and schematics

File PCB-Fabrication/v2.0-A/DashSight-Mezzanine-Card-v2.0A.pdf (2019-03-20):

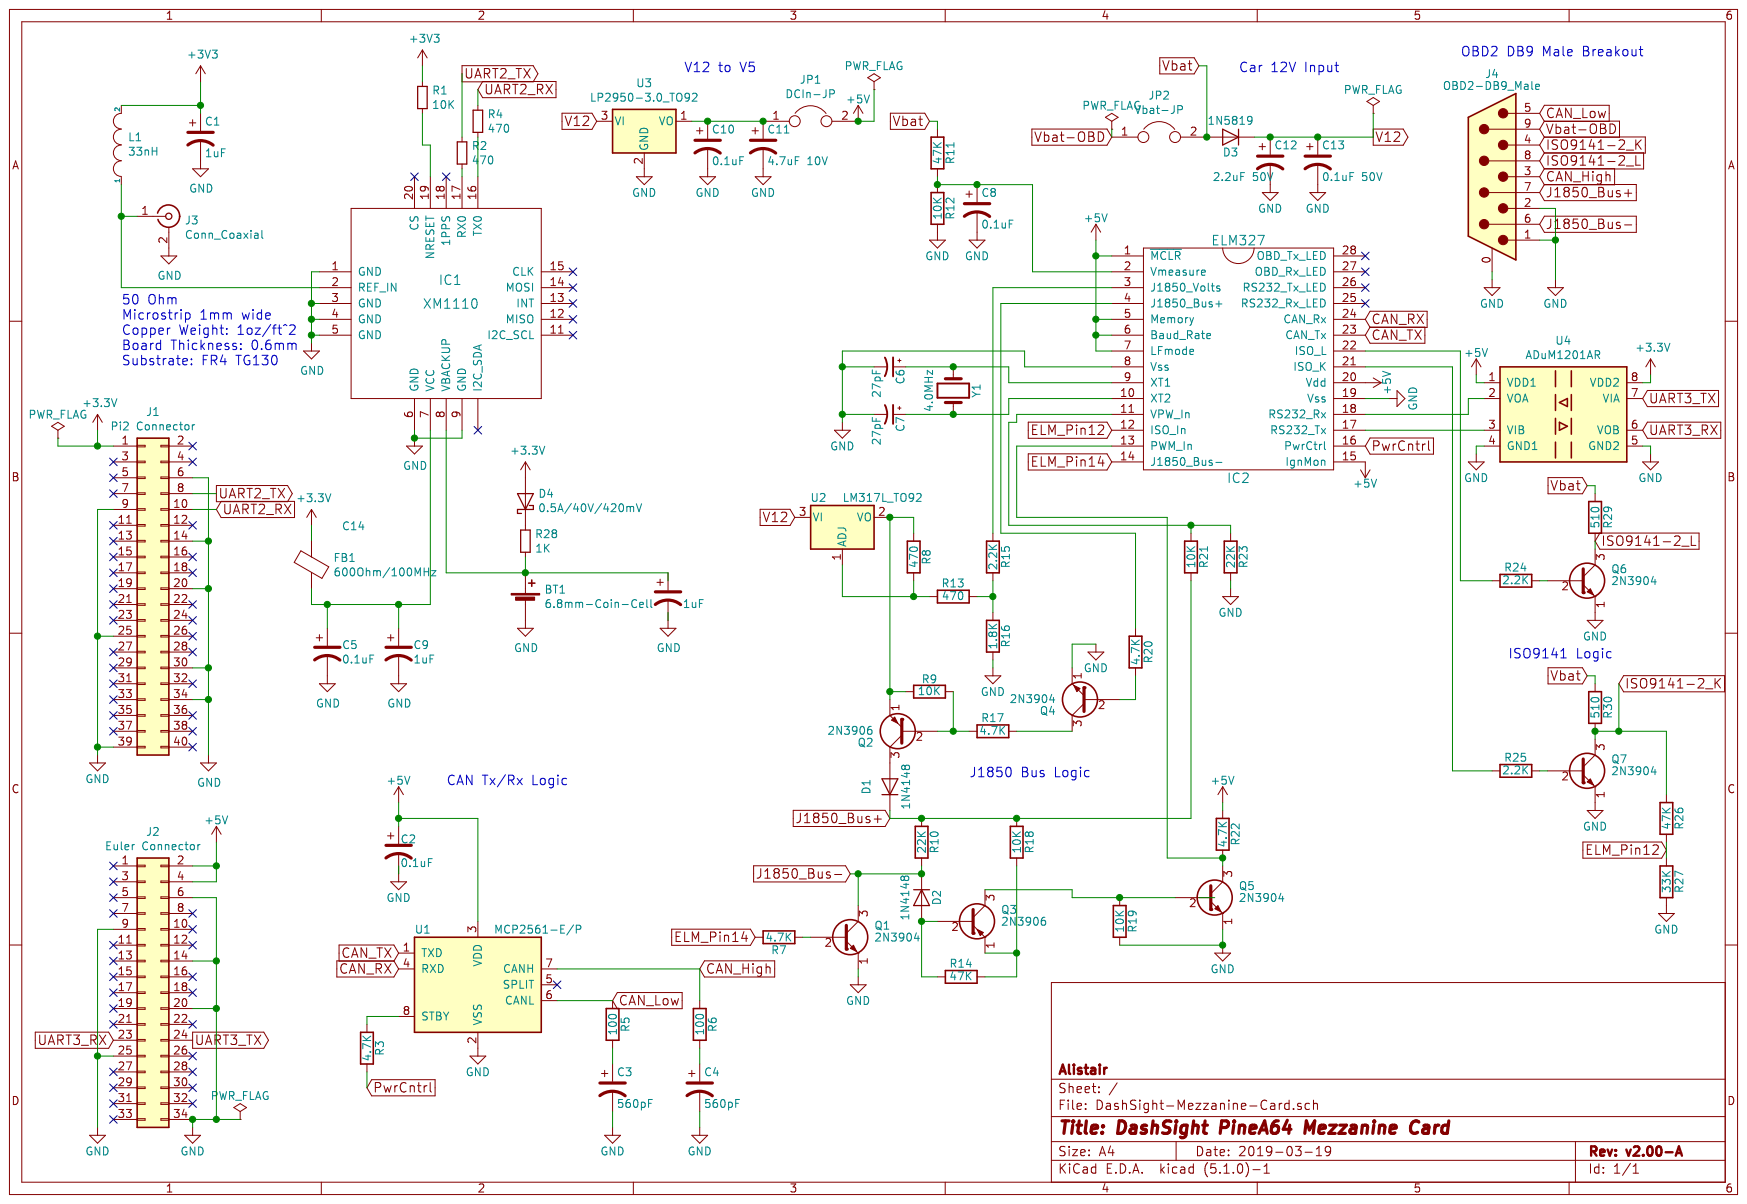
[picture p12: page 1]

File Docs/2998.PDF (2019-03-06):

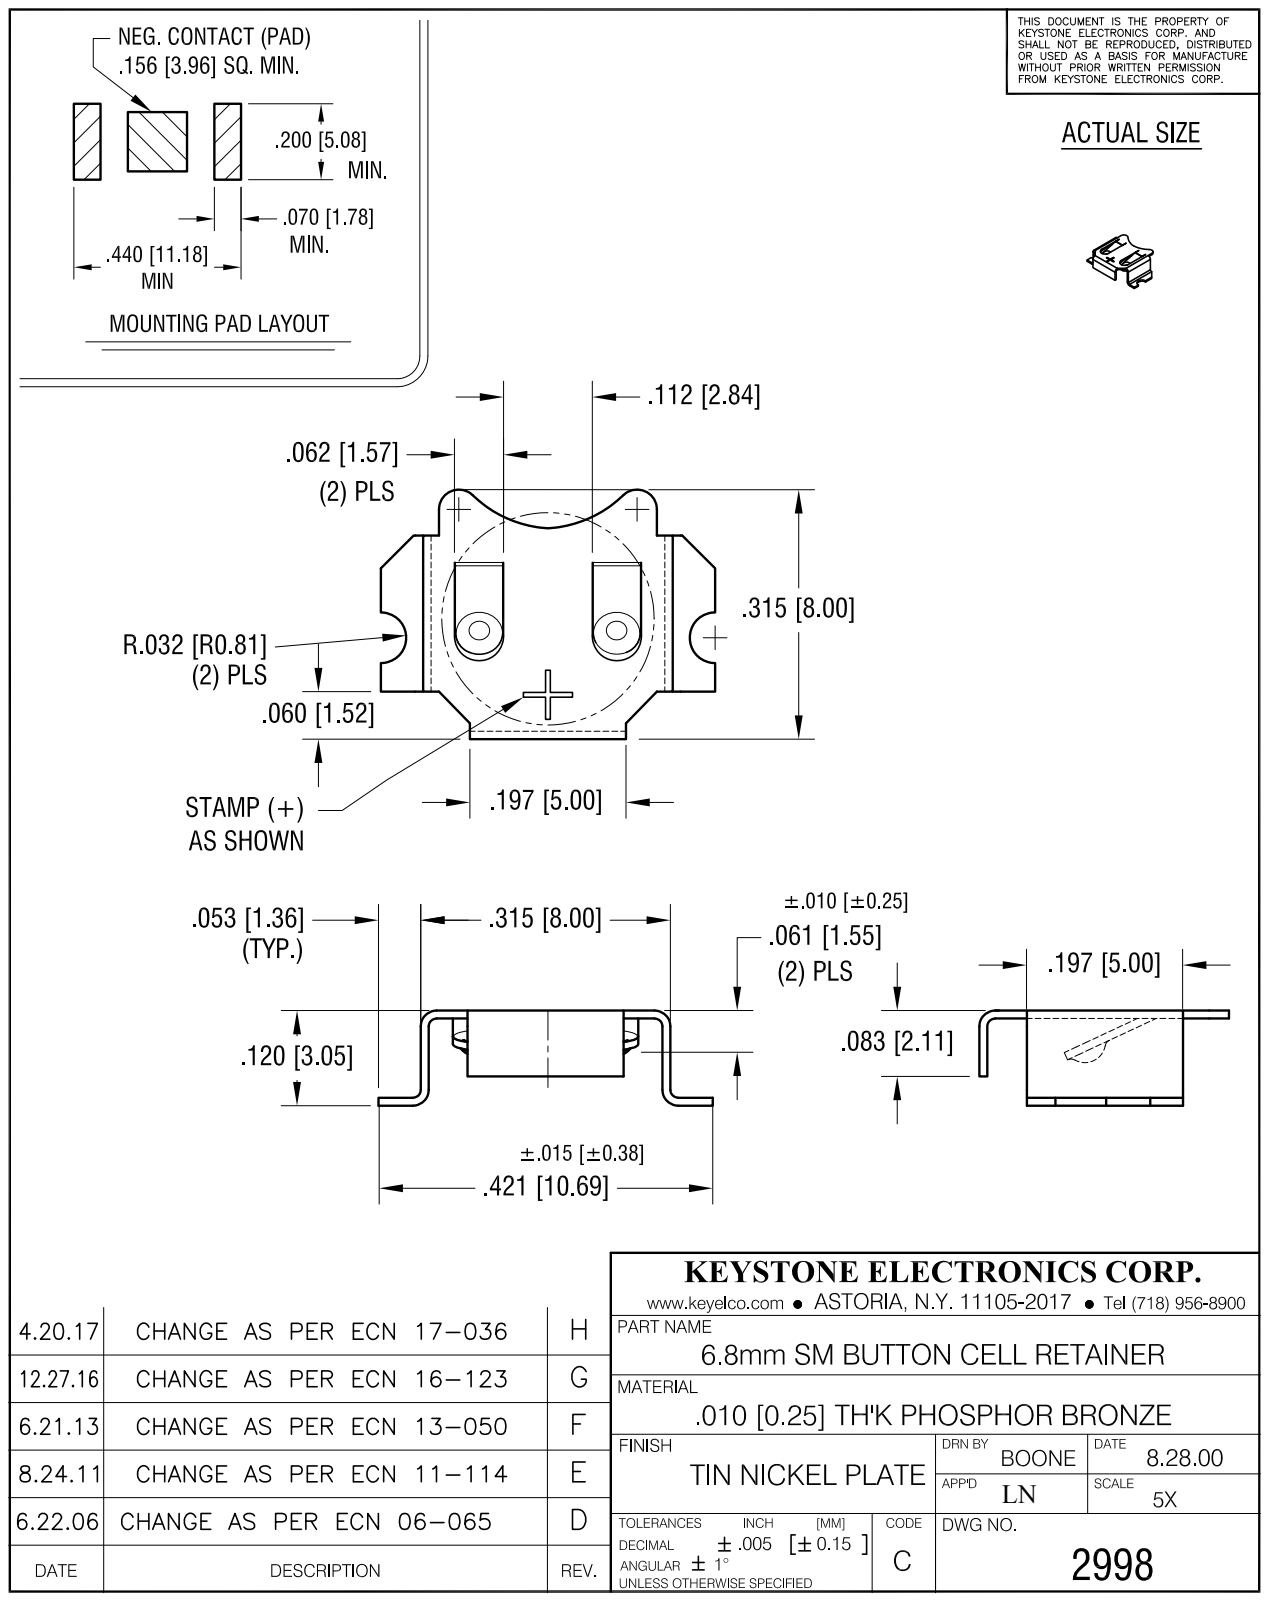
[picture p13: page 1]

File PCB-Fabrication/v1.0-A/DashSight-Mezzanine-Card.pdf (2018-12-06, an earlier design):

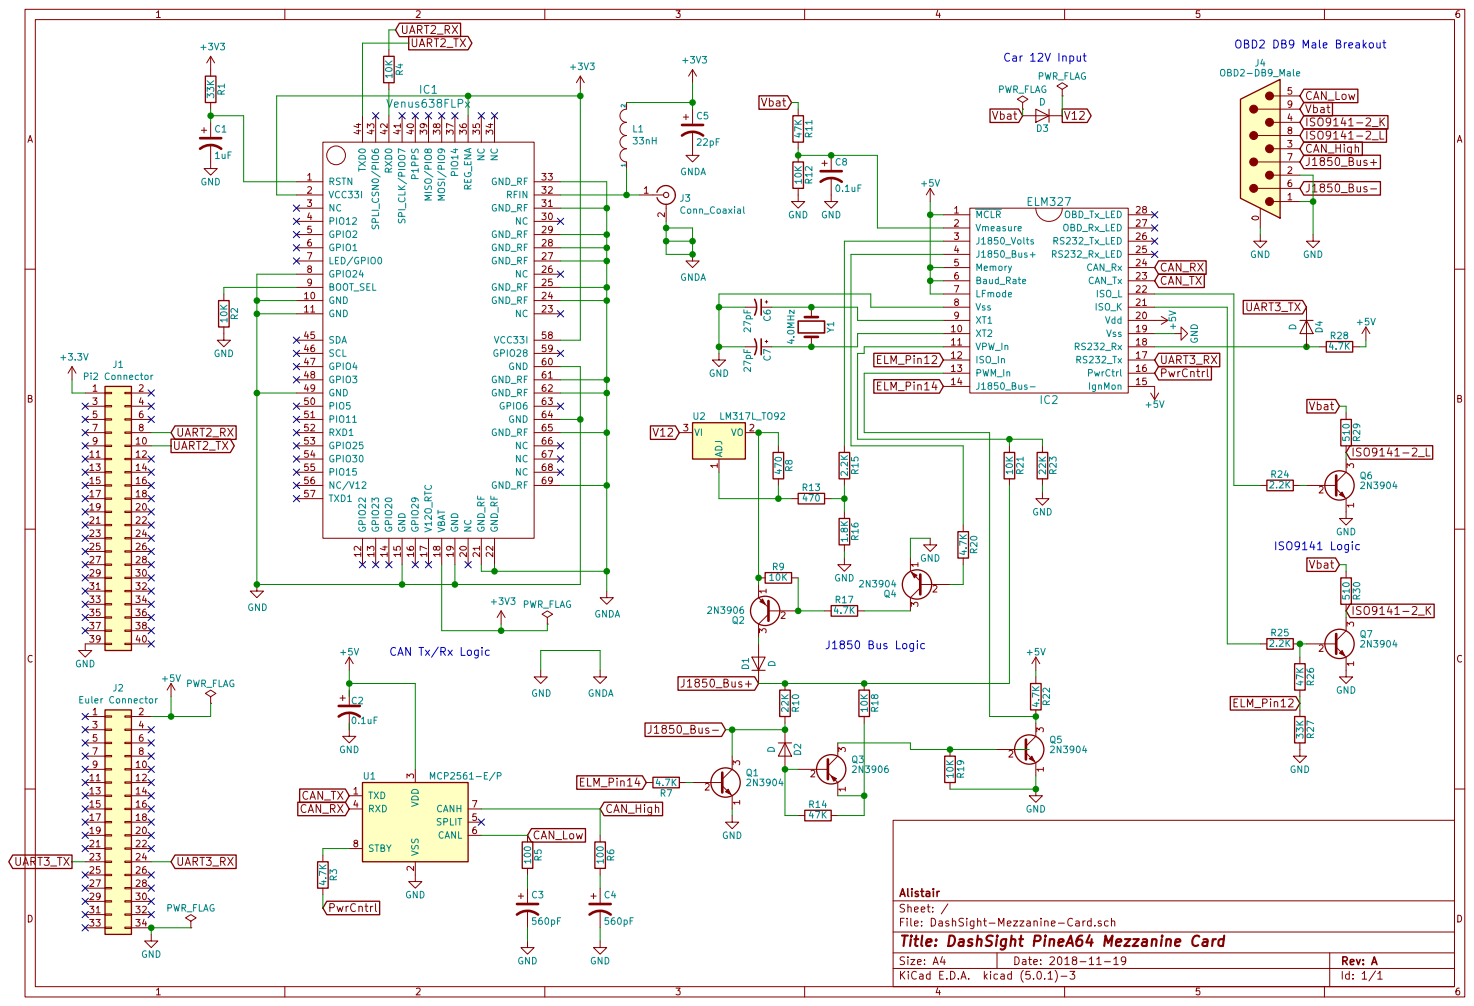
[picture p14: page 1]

3 RXD 4 SPLIT 5 CANL 6 CANH 7 STBY 8 U1 MCP2561-E/P CAN_RX

File: DashSight-Mezzanine-Card.sch Sheet: / Alistair GND

Id: 1/1 Title: DashSight PineA64 Mezzanine Card

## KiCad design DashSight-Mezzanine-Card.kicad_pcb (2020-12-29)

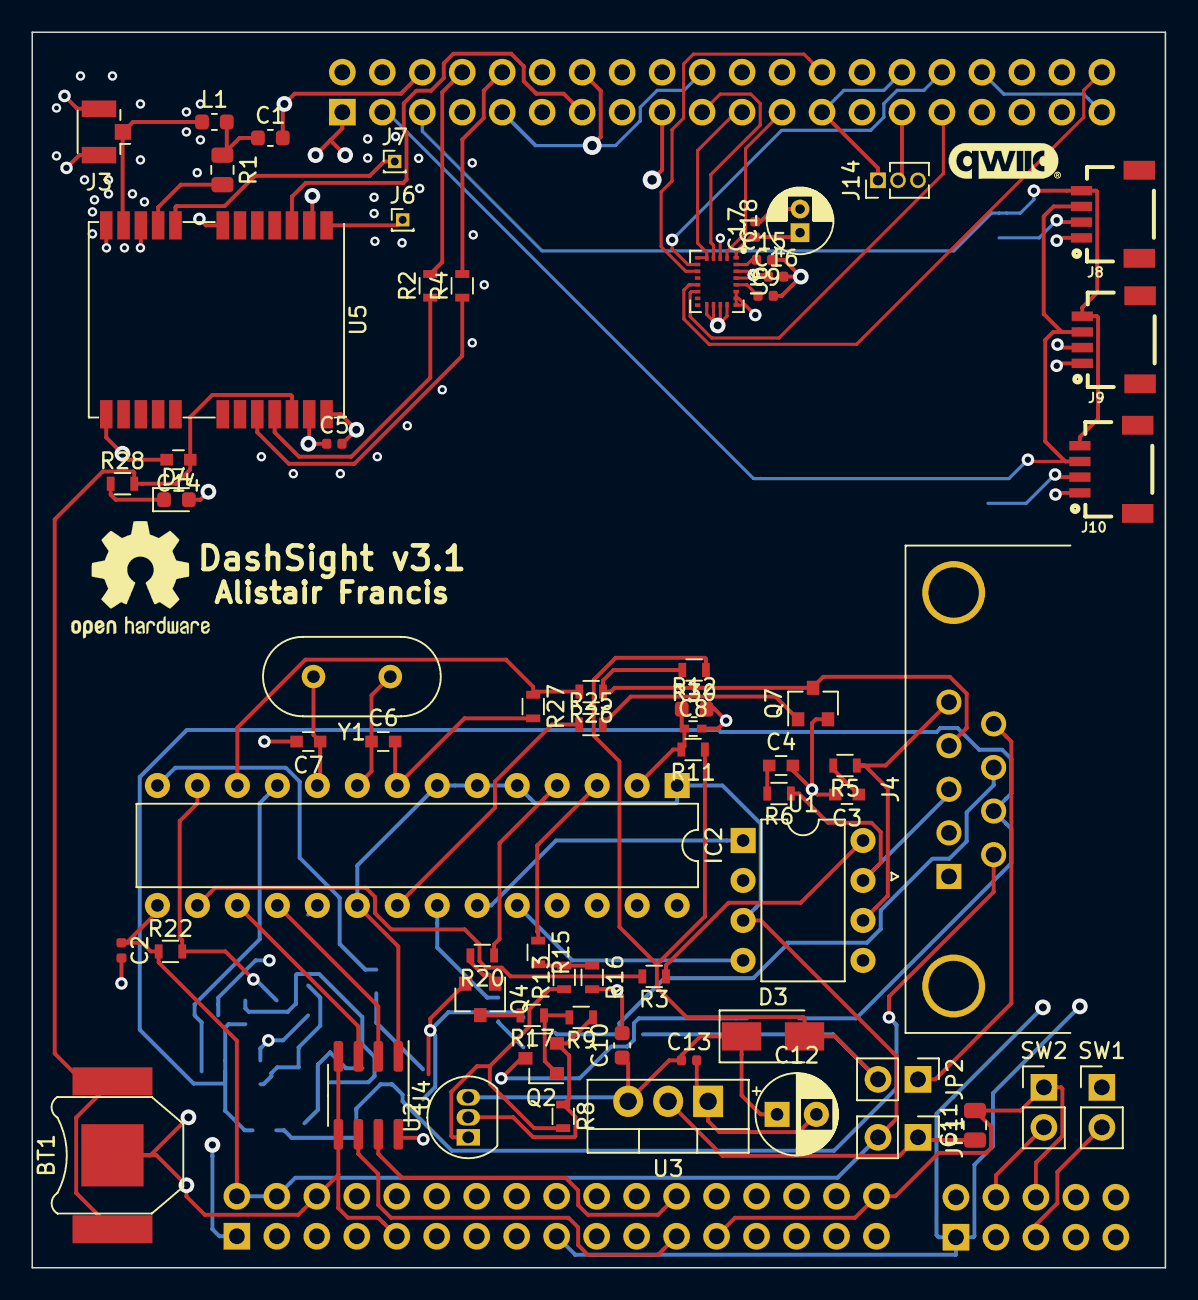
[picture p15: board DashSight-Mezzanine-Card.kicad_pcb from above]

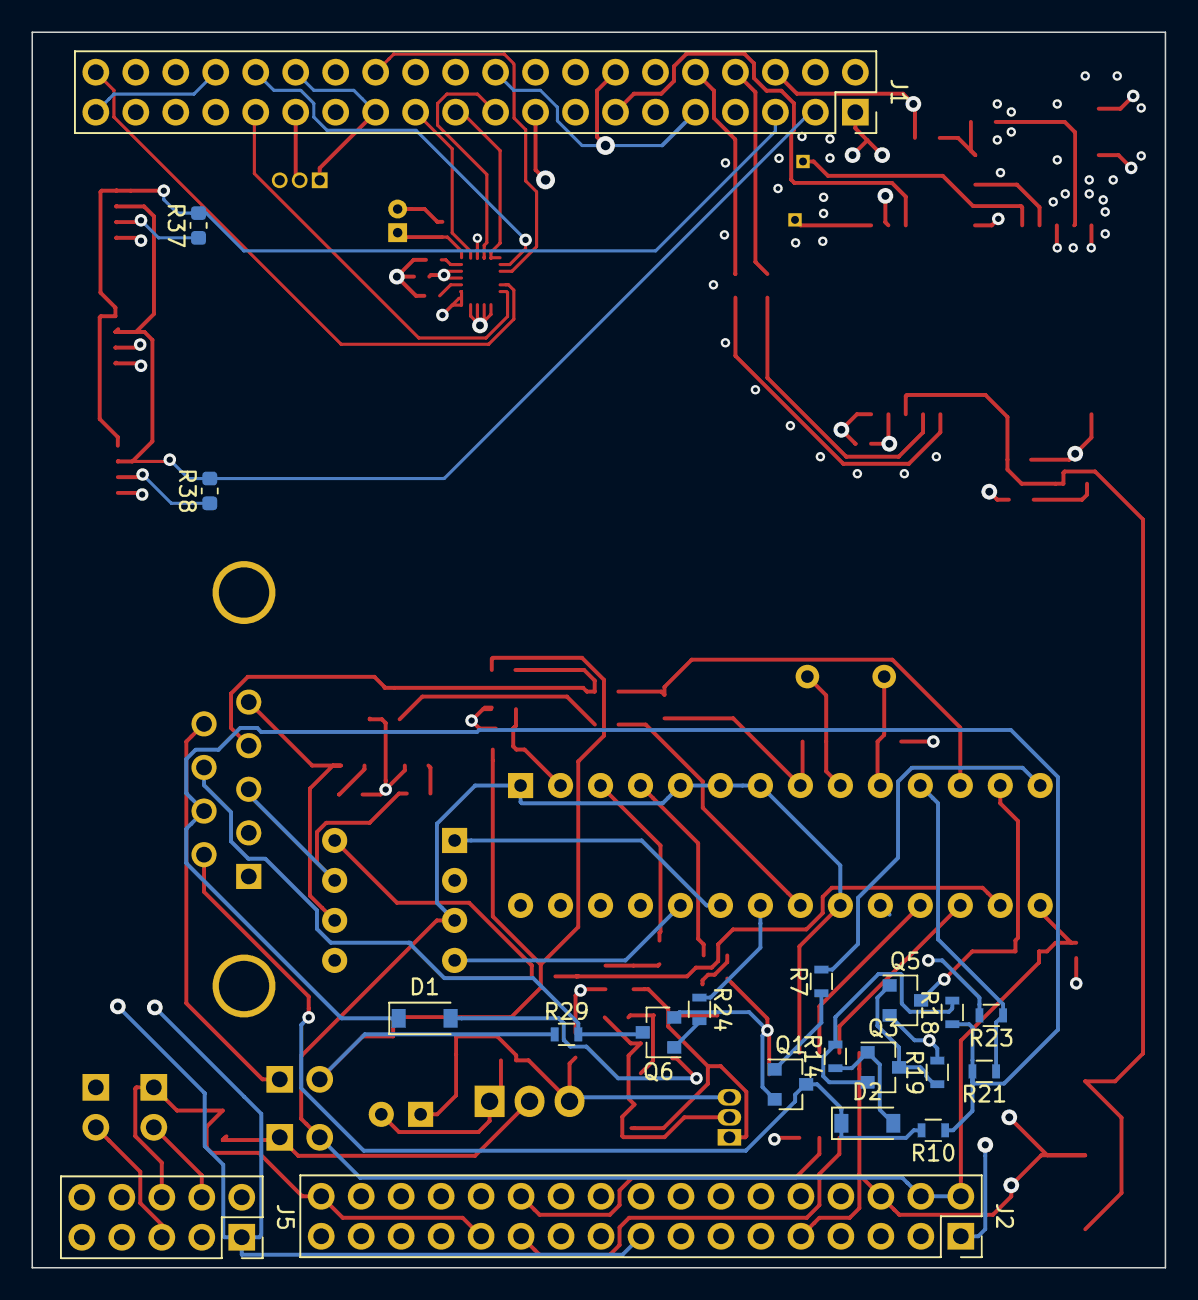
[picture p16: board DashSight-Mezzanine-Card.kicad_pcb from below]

Board: 4 copper layers, 72.0 x 78.5 mm, 86 parts (20 on the bottom side), 73 nets.

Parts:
BT1: 6.8mm-Coin-Cell; BatteryHolder_Keystone_2998_1x6.8mm
C1: 47pF; C_0603_1608Metric
C2, C5, C15, C16, C17: 0.1uF; C_0402_1005Metric
C3, C4: 560pF; C_0603
C6, C7: 27pF; C_0603
C8: 0.1uF; C_0402
C9: 10nF (16V); C_0402_1005Metric
C10: 10uF; C_0603_1608Metric
C11: 10uF 10V; C_0805_2012Metric
C12: 2.2uF 50V; CP_Radial_D5.0mm_P2.50mm
C13: 0.1uF 50V; C_0402_1005Metric
C14: 1uF; C_0603
C18: 10uF; CP_Radial_D4.0mm_P1.50mm
D1, D2: 1N4148; D_SOD-123
D3: 1N5819; D_SMA
D4: 0.5A/40V/420mV; D_0603_1608Metric
IC2: ELM327; DIP-28_W7.62mm
J1: Pi2 Connector; PinSocket_2x20_P2.54mm_Vertical
J2: Euler Connector; PinSocket_2x17_P2.54mm_Vertical
J3: Conn_Coaxial; U.FL_Hirose_U.FL-R-SMT-1_Vertical
J4: OBD2-DB9_Male; DSUB-9_Male_Horizontal_P2.77x2.84mm_EdgePinOffset4.94mm_Hou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
J5: Conn_02x05_Odd_Even; PinSocket_2x05_P2.54mm_Vertical
J6: Safeboot; PinHeader_1x01_P1.00mm_Vertical
J7: Reset; PinHeader_1x01_P1.00mm_Vertical
J8, J9, J10: QWIIC_CONNECTORJS-1MM; qwiic_connector
J14: 1W-PC16; PinHeader_1x03_P1.27mm_Vertical
JP1: DCIn-JP; PinHeader_1x02_P2.54mm_Vertical
JP2: Vbat-JP; PinHeader_1x02_P2.54mm_Vertical
L1: 30Ohm/1.8A; L_0603_1608Metric
Q1, Q4, Q5, Q6, Q7: 2N3904; SOT-23
Q2, Q3: 2N3906; SOT-23
R1: 10; R_0805_2012Metric
R2, R4, R8, R13: 470; R_0603
R3, R7, R17, R20, R22: 4.7K; R_0603
R5, R6: 100; R_0603
R9, R18, R19, R21: 10K; R_0603
R10, R23: 22K; R_0603
R11, R14, R26: 47K; R_0603
R12: 10K; R_0603_1608Metric
R15, R24, R25: 2.2K; R_0603
R16: 1.8K; R_0603
R27: 33K; R_0603
R28: 1K; R_0603
R29, R30: 510; R_0603
R37, R38: 2.2K; R_0603_1608Metric
SW1, SW2: SW_Push; PinHeader_1x02_P2.54mm_Vertical
U1: MCP2561-E/P; DIP-8_W7.62mm
U2: LM317L_TO92; TO-92_Inline
U3: LM1085IT-5.0; TO-220-3_Vertical
U4: ADuM1201AR; SOIC-8_3.9x4.9mm_P1.27mm
U5: NEO-M9N; ublox_NEO
U6: LSM9DS1; LGA-24L_3x3.5mm_P0.43mm
Y1: 4.0MHz; Crystal_HC49-U_Vertical

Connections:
+3V3: C5.1, C16.1, C17.1, C18.1, D4.2, J1.1, J1.17, J2.1, J2.17, J5.1, J8.2, J9.2, J10.2, J14.3, R37.1, R38.1, SW1.1, U4.8, U5.2, U5.23, U6.1, U6.3, U6.22, U6.23
+5V: C2.1, IC2.1, IC2.5, IC2.6, IC2.7, IC2.15, IC2.20, J2.2, J2.4, JP1.2, R22.1, U1.3, U4.1
CAN_High: J4.3, R6.1, U1.7
CAN_Low: J4.5, R5.1, U1.6
CAN_RX: IC2.24, U1.4
CAN_TX: IC2.23, U1.1
ELM_Pin12: IC2.12, R26.2, R27.1
ELM_Pin14: IC2.14, R7.2
GND: BT1.2, C1.2, C2.2, C3.2, C4.2, C5.2, C6.2, C7.2, C8.2, C9.2, C10.2, C11.2, C12.2, C13.2, C14.2, C15.2, C16.2, C17.2, C18.2, IC2.8, IC2.19, J1.6, J1.9, J1.14, J1.20, J1.25, J1.30, J1.34, J1.39, J2.6, J2.9, J2.14, J2.20, J2.25, J2.34, J3.2, J4.0, J4.1, J4.2, J5.6, J5.9, J8.1, J9.1, J10.1, J14.1, Q1.2, Q4.2, Q5.2, Q6.2, Q7.2, R12.2, R16.2, R19.2, R23.2, R27.2, SW2.1, U1.2, U3.1, U4.4, U4.5, U5.7, U5.10, U5.12, U5.13, U5.24, U6.14, U6.15, U6.16, U6.17, U6.18, U6.19, U6.20
I2C1_SCL: J1.5, J8.4, J9.4, J10.4, R37.2
I2C1_SDA: J1.3, J8.3, J9.3, J10.3, R38.2
ISO9141-2_K: J4.4, Q7.3, R26.1, R30.2
ISO9141-2_L: J4.8, Q6.3, R29.2
J1850_Bus+: D1.1, J4.7, R10.1, R18.1, R21.2
J1850_Bus-: D2.1, J4.6, Q1.3, R10.2
unnamed: BT1.1, C14.1, R28.2, U5.22
unnamed: C1.1, L1.2, R1.1
unnamed: C3.1, R5.2
unnamed: C4.1, R6.2
unnamed: C6.1, IC2.9, Y1.1
unnamed: C7.1, IC2.10, Y1.2
unnamed: C8.1, IC2.2, R11.2, R12.1
unnamed: C9.1, U6.21
unnamed: C11.1, JP1.1, U3.2
unnamed: C15.1, U6.24
unnamed: D1.2, Q2.3
unnamed: D2.2, Q3.1, R14.1
unnamed: D4.1, R28.1
unnamed: IC2.3, R15.1
unnamed: IC2.4, R20.1
unnamed: IC2.11, R21.1, R23.1
unnamed: IC2.13, Q5.3, R22.2
unnamed: IC2.17, U4.3
unnamed: IC2.18, U4.2
unnamed: IC2.21, R25.1
unnamed: IC2.22, R24.1
unnamed: J3.1, L1.1, U5.11
unnamed: J6.1, U5.1
unnamed: J7.1, U5.8
unnamed: Q1.1, R7.1
unnamed: Q2.1, R9.2, R17.1
unnamed: Q2.2, R8.1, R9.1, U2.2
unnamed: Q3.2, R14.2, R18.2
unnamed: Q3.3, Q5.1, R19.1
unnamed: Q4.1, R20.2
unnamed: Q4.3, R17.2
unnamed: Q6.1, R24.2
unnamed: Q7.1, R25.2
unnamed: R1.2, U5.9
unnamed: R2.1, U5.21
unnamed: R3.1, U1.8
unnamed: R4.1, U5.20
unnamed: R8.2, R13.1, U2.1
unnamed: R13.2, R15.2, R16.1
PC4: J1.32, U6.7
PC11: J1.40, U6.10
PH5: J1.29, J14.2
PH6: J1.31, U6.11
PH7: J1.26, U6.8
PH9: J1.13, U5.3
PowerOn: J5.5, SW1.2
PwrCntrl: IC2.16, R3.2
ResetSW: J5.4, SW2.2
SPI0_CLK: J1.23, U6.2
SPI0_MISO: J1.21, U6.5, U6.6
SPI0_MOSI: J1.19, U6.4
UART2_RX: J1.10, R4.2
UART2_TX: J1.8, R2.2
UART3_RX: J2.23, U4.6
UART3_TX: J2.24, U4.7
V12: C10.1, C12.1, C13.1, D3.1, U2.3, U3.3
Vbat: D3.2, JP2.2, R11.1, R29.1, R30.1
Vbat-OBD: J4.9, JP2.1

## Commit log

2018-01-20 Initial Commit
    This is the initial commit based on the template avaliable here:
    https://github.com/96boards/96boards-kicad-mezzanine-template
    [OBD2-Mezzanine-Card.kicad_pcb, OBD2-Mezzanine-Card.sch]
2018-01-20 sch: Change to a through-hole non-stackable pin header
    [OBD2-Mezzanine-Card.sch]
2018-01-20 sch: Delete Linaro notes
    [OBD2-Mezzanine-Card.sch]
2018-03-12 lib: Add the ELM327 component
    [OBD2-Mezzanine-Card.sch]
2018-03-12 sch: Update the title
    [OBD2-Mezzanine-Card.sch]
2018-03-12 sch: Connect the Light Emitting Diodes
    [OBD2-Mezzanine-Card.sch]
2018-03-12 sch: Connect some of the power options
    [OBD2-Mezzanine-Card.sch]
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2018-03-12 sch: Add the MCP2561 CAN Transceiver
    [OBD2-Mezzanine-Card.sch]
2018-03-12 sch: Start to connect the CAN transceiver
    [OBD2-Mezzanine-Card.sch]
2018-03-12 sch: Add some more connections
    [OBD2-Mezzanine-Card.sch]
2018-03-12 sch: Fixup a mistake
    [OBD2-Mezzanine-Card.sch]
2018-03-15 sch: Add the OBD2 breakout
    [OBD2-Mezzanine-Card.sch]
2018-03-15 sch: Connect the CAN High/Low to the ODB2
    [OBD2-Mezzanine-Card.sch]
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2018-03-15 sch: Initial commit of J1850 positivie bus
    [OBD2-Mezzanine-Card.sch]
2018-03-15 sch: Rearange the schematic
    [OBD2-Mezzanine-Card.sch]
2018-03-15 sch: Connect the J1850 Bus
    [OBD2-Mezzanine-Card.sch]
2018-03-15 scho: Rearange a little bit
    [OBD2-Mezzanine-Card.sch]
2018-03-15 sch: Fix duplicate label
    [OBD2-Mezzanine-Card.sch]
2018-03-15 sch: Connect the ISO9141-2 connections
    [OBD2-Mezzanine-Card.sch]
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2018-03-15 sch: Add the 12volt power supply
    Also rearrange a bit more
    [OBD2-Mezzanine-Card.sch]
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2018-03-15 sch: Misc fixes to try to fix electrical checks
    [OBD2-Mezzanine-Card.sch]
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2018-03-15 sch: Pass all electrical checks and add some lables
    Schematic is ready for review.
    [OBD2-Mezzanine-Card.sch]
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2018-03-20 sch: Add PCB footprints to most parts
    [OBD2-Mezzanine-Card.sch]
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2018-03-21 sch: Finalise the PCB footprints
    [OBD2-Mezzanine-Card.sch]
2018-03-21 sch: Fix up the some PCB footprints
    [OBD2-Mezzanine-Card.sch]
2018-03-21 kicad_pcd: Start to put the PCB together
    [OBD2-Mezzanine-Card.kicad_pcb]
2018-03-21 kicad_pcb: Start to connect tracks
    [OBD2-Mezzanine-Card.kicad_pcb]
2018-03-21 kicad_pcb: Continue to connect tracks
    [OBD2-Mezzanine-Card.kicad_pcb]
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2018-05-16 kicad_pcb: Connect a large number of PCB devices
    [OBD2-Mezzanine-Card.kicad_pcb]
2018-11-17 DashSight: Convert from 96boards project to PineA64
    [DashSight-Mezzanine-Card-2018-11-17-09-13-31.sch, DashSight-Mezzanine-Card.sch, OBD2-Mezzanine-Card.kicad_pcb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]
2018-11-20 sch: Update for the new Pine board
    [DashSight-Mezzanine-Card.sch]
2018-11-21 Update with the GPS IC
    [DashSight-Mezzanine-Card.sch]
2018-11-21 More GPS connection updates
    [DashSight-Mezzanine-Card.sch]
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2018-11-22 pcb: Add initial PCB
    [DashSight-Mezzanine-Card.kicad_pcb]
2018-11-22 sch: Update PCB components
    [DashSight-Mezzanine-Card.sch]
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2018-11-22 sch: Finish setting the PCB footprints
    [DashSight-Mezzanine-Card.sch]
2018-11-22 sch: Fix wrong number of pins
    [DashSight-Mezzanine-Card.sch]
2018-11-22 pcb: Add all the modules
    [DashSight-Mezzanine-Card.kicad_pcb]
2018-11-22 pcb: Kind of layout the board
    [DashSight-Mezzanine-Card.kicad_pcb]
2018-11-22 Show orientation of Venus IC and update PCB
    [DashSight-Mezzanine-Card.kicad_pcb]
2018-11-22 pcb: Continue improving layout
    [DashSight-Mezzanine-Card.kicad_pcb]
2018-11-22 pcb: Start to connect the tracks
    [DashSight-Mezzanine-Card.kicad_pcb]
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2018-11-25 sch: Fix capacitor BOM
    [BOM.xls, DashSight-Mezzanine-Card.sch]
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2018-12-01 BOM: Change ELM IC to a IC socket instead
    [BOM.csv, DashSight-Mezzanine-Card.sch]
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2019-02-21 Revert "pdf: Remove old schematic"
    This reverts commit 697014c673d4359312c34be824b0650e6c1d6efa, but moves
    the schematic into the PCB-Fabrication sub directory.
2019-02-21 sch: Update the J1850 bus diodes to match the ELM327 datasheet
    [DashSight-Mezzanine-Card.sch]
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2019-03-06 sch: Fix connection errors
    [DashSight-Mezzanine-Card.sch]
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2019-03-06 sch: Revert the annotation
    [DashSight-Mezzanine-Card.sch]
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2019-03-11 sch: Update PCB thickness and track width for RF
    [DashSight-Mezzanine-Card.sch]
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2019-03-17 PCB: Reduce antenna distance and regenerate production files
    [DashSight-Mezzanine-Card-B_Cu.gbl, DashSight-Mezzanine-Card-B_Mask.gbs, DashSight-Mezzanine-Card-B_SilkS.gbo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]
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2019-05-14 sch: Fix the Antenna connector part
    [DashSight-Mezzanine-Card.sch]
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2019-07-26 pcb: Replace with the new voltage regulator
    [DashSight-Mezzanine-Card.kicad_pcb]
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2020-04-09 sch: Fixup missing components
    [DashSight-Mezzanine-Card.sch]
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2020-04-10 sch: Add a button to turn the board on
    [DashSight-Mezzanine-Card.sch]
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2020-04-10 sch: Small fixups in the layout
    [DashSight-Mezzanine-Card.sch]
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2020-04-11 pcb: Upgrade to 4 layers and start to prep GNSS
    [DashSight-Mezzanine-Card.kicad_pcb]
2020-04-11 pcb: Add ground and power planes on inner layers
    [DashSight-Mezzanine-Card.kicad_pcb]
2020-04-11 sch: Add a power decoupling cap for GNSS 3V3
    [DashSight-Mezzanine-Card.sch]
2020-04-11 pcb: Start to connect up the GNSS receiver
    [DashSight-Mezzanine-Card.kicad_pcb]
2020-04-12 sch: Fix the reset button connection
    [DashSight-Mezzanine-Card.sch]
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2020-04-12 sch: Fixup some errors
    [DashSight-Mezzanine-Card.sch]
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2020-04-25 sch: Fixup resistor types
    [DashSight-Mezzanine-Card.sch]
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2020-04-28 pcb: Connect the IMU, GNSS PPS, Qwiic and other changes
    [DashSight-Mezzanine-Card.kicad_pcb]
2020-04-28 Breakout some GPIOs and fixup remaining issues
    [DashSight-Mezzanine-Card.kicad_pcb, DashSight-Mezzanine-Card.sch]
2020-04-28 pcb: Small corrections
    [DashSight-Mezzanine-Card.kicad_pcb]
2020-04-28 Only support 6 Qwiic connections
    I was worried I couuldn't fit the cables in with 6
    [DashSight-Mezzanine-Card.kicad_pcb, DashSight-Mezzanine-Card.sch]
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2020-04-29 sch: Add a jumper to enable SPI for the IMU
    [DashSight-Mezzanine-Card.sch]
2020-04-29 Revert "sch: Add a jumper to enable SPI for the IMU"
    This reverts commit a1cdc124bf6f11fea9068c468dfdf75d15ab77d8.
    [DashSight-Mezzanine-Card.sch]
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2020-05-01 Revert "Revert "sch: Add a jumper to enable SPI for the IMU""
    This reverts commit c516a7607144a3527f6f3ebaa38245544a61c706.
    [DashSight-Mezzanine-Card.sch]
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2020-05-03 PCB-Fab: Update the files for the v3.0 production
    [DashSight-Mezzanine-Card-B_Cu.gbl, DashSight-Mezzanine-Card-B_Mask.gbs, DashSight-Mezzanine-Card-B_Paste.gbp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]
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2020-05-19 PCB-Fab: Add some position files used for v0.3
    [DashSight-Mezzanine-Card-all-pos.csv]
2020-09-12 sch: Fixup some of the component types
    [DashSight-Mezzanine-Card.sch]
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2020-09-12 sch/pcb: Update the GPS connected to U.FL
    Also fixup some missing connections and bump PCB and schematic
    versions.
    [DashSight-Mezzanine-Card.kicad_pcb, DashSight-Mezzanine-Card.sch]
2020-10-14 sch: Fix the BJT Transistors
    [DashSight-Mezzanine-Card.sch]
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2020-11-05 sch: Use shorter headers
    [DashSight-Mezzanine-Card.sch]
2020-12-29 sch: Fix the PPS GPIO to be interrupt capable
    [DashSight-Mezzanine-Card.sch]
2020-12-29 kicad_pcb: Update the PCB based on the new schematic
    [DashSight-Mezzanine-Card.kicad_pcb]
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
